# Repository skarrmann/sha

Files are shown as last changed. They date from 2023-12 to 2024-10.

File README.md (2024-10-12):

# Sha Keyboard

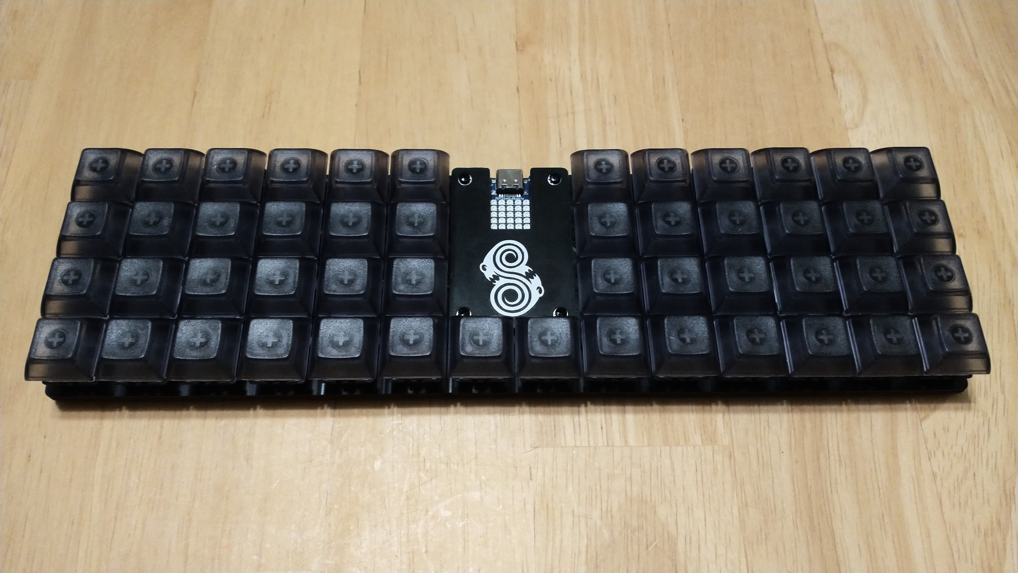
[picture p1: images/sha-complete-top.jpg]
Sha complete build top photo


Sha is a 50 key ortholinear keyboard, powered by either a [Waveshare RP2040-Zero](https://www.waveshare.com/rp2040-zero.htm) or [Waveshare RP2040-Matrix](https://www.waveshare.com/product/rp2040-matrix.htm).

## Project structure

* [`gerbers`](gerbers): Gerber files for PCB manufacturing
* [`graphics`](graphics): Source assets for PCB silkscreen
* [`kicad`](kicad): KiCad project files (schematics and PCB designs)
* [`kicad-libraries`](kicad-libraries): KiCad components and footprints
* [`images`](images): Images for project documentation
* [`firmware`](firmware): Firmware files

## PCBs

Two separate PCB designs are available for MX and Choc keyswitches, with their respective footprints and key spacing (MX: 19mm x 19mm, Choc: 18mm x 17mm).

The Waveshare RP2040-Zero/Matrix footprint uses surface-mount solder pads. The castellated pads of the MCU board are soldered directly onto the PCB.

**Each build uses two copies of the main PCB**. This PCB acts as both the logical PCB, and when flipped the long way, it acts as a bottom plate to be attached the logical PCB.

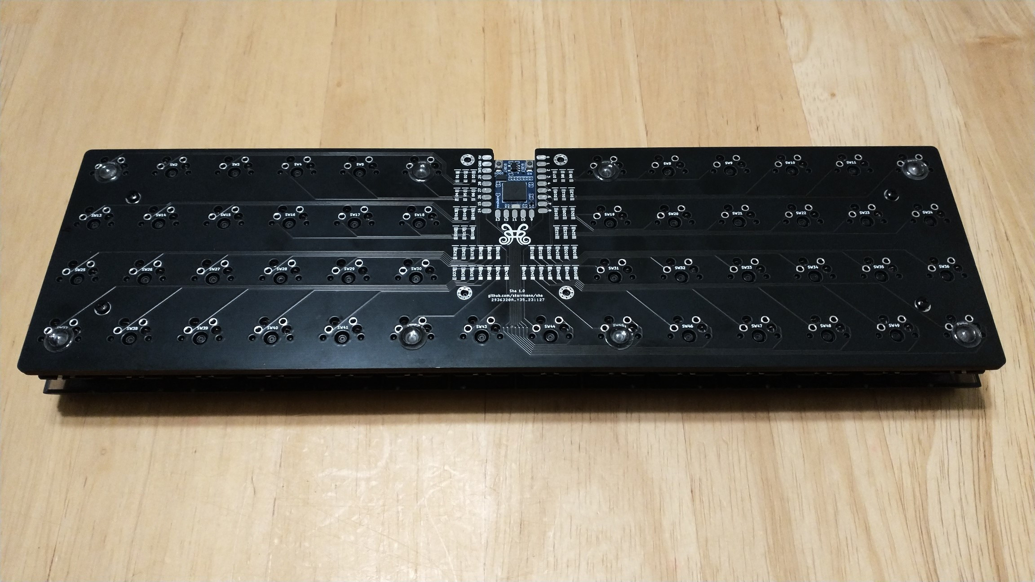
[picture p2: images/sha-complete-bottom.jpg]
Sha bottom plate attached


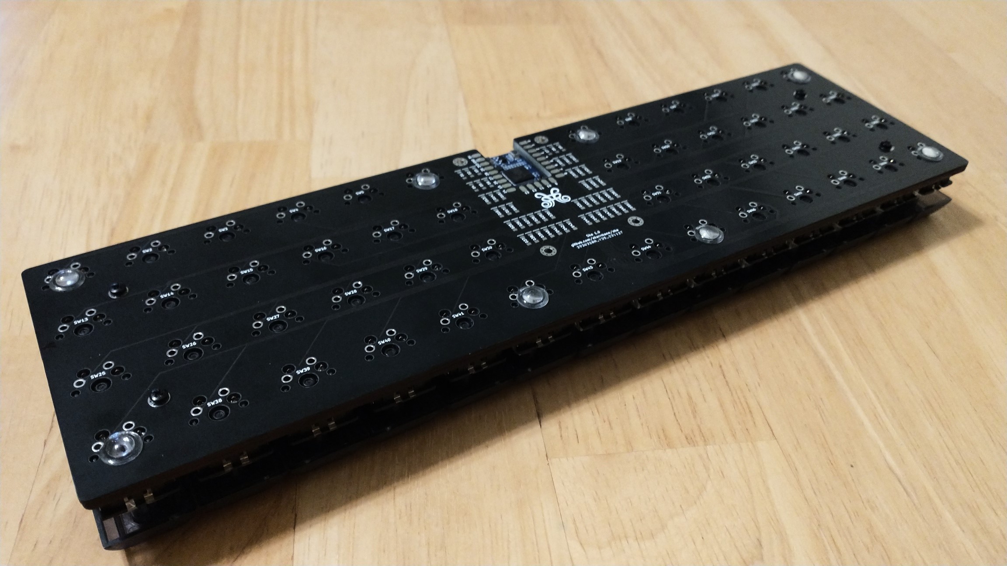
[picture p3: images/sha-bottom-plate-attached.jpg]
Sha bottom plate alternate shot


An optional top plate PCB is available in the gerber files. This top plate covers the diodes and the solder pads of the MCU board.

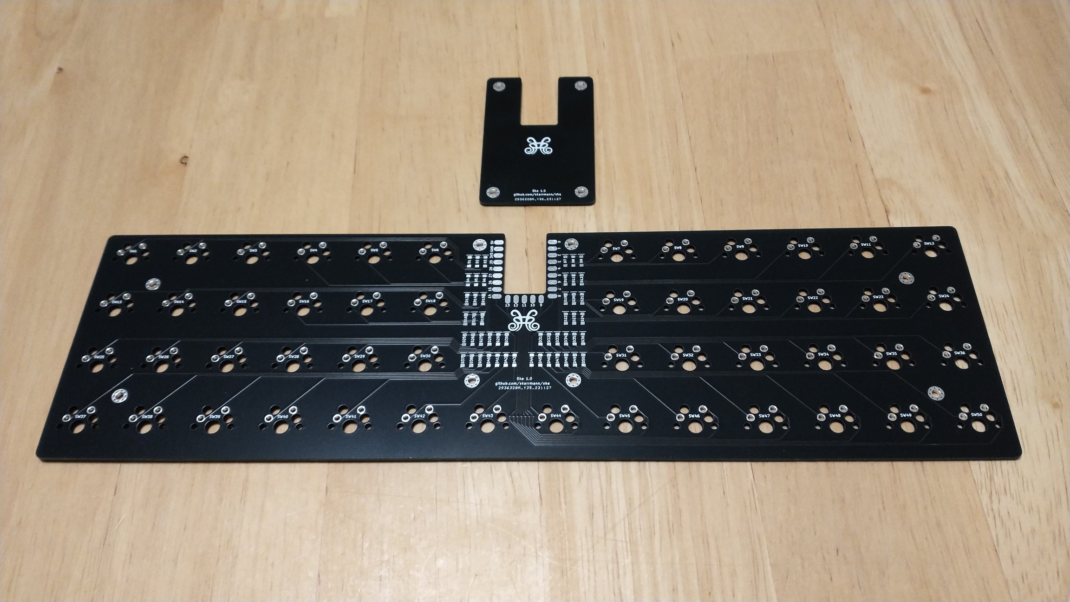
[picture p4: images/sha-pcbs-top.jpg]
Sha main and top plate PCBs


## Keyboard firmware

* KMK
    * Setup instructions and basic configuration is in this repo: [`firmware/kmk`](firmware/kmk)
* [QMK](https://github.com/qmk/qmk_firmware/tree/master/keyboards/sha)

## Bill of materials

Part | Purpose | Quantity | Notes
---- | ------- | -------- | -----
Main PCB  | circuit board and bottom plate | 2 | Send Gerber zip files to [JLCPCB](https://jlcpcb.com/)
Top plate PCB | protects diodes and MCU board | 1 |
Waveshare RP2040-Zero | Microcontroller board | 1 | Also supports Waveshare RP2040-Matrix
1N4148 SOD-123 | Diodes for keyboard row-column matrix | 50 |
Keyswitches |  | 50 | PCB mount (5 pin) switches recommended. For MX, any switches should work. For Choc, get Choc V1 switches.
Keycaps |  | 50 | For MX, any keycaps should work. For Choc, get those which fit Choc V1 18mm x 17mm
M2 6mm screws | 4 to secure main PCB and bottom plate PCB, 4 for top plate | 8 |
M2 nuts | 4 to secure main PCB and bottom plate PCB, 4 as spacers for top plate | 8 |
2mm tall rubber bumpons | Raise board above desk surface and provide skid resitance | 8 | 

Note the 4 M2 6mm screws and 4 M2 nuts just "friction fit" the top plate. To fully screw in the top plate, You could use 4 M2 8mm+ screws and 4 more M2 nuts. I meant to do this, but accidentally ordered the wrong size screws...!

## PCB manufacturing settings

These are the manufacturing settings I used when ordering from JLCPCB:

* **Base Material**: FR4
* **Layers**: 2
* **Dimensions**: (whatever the gerber file specifies)
* **PCB Qty**: 5
* **Different Design**: 1
* **Delivery Format**: Single PCB
* **PCB Thickness**: 1.6
* **PCB Color**: Black
* **Silkscreen**: White
* **Surface Finish**: LeadFree HASL-RoHS
* **Outer Copper Weight**: 1 oz
* **Gold Fingers**: No
* **Confirm Production File**: No
* **Flying Probe Test**: Fully Test
* **Castellated Holes**: No
* **Remove Order Number**: Specify a location

**IMPORTANT:** The PCB has ["JLCJLCJLCJLC" silkscreen text](https://jlcpcb.com/help/article/50-How-to-remove-order-number-from-your-PCB) on top side of the board. If you want to remove the order number from the boards or you want to print the PCBs with another manufacturer, then I recommend removing this silkscreen text from the `.kicad_pcb` file, and then regenerate the Gerber files.

## Build tips

* Solder the diodes first. Tin one side of all the diode solder pads, and then position each diode and re-heat this tinned pad to tack the diode in place. Then solder the other diode leg on each diode.
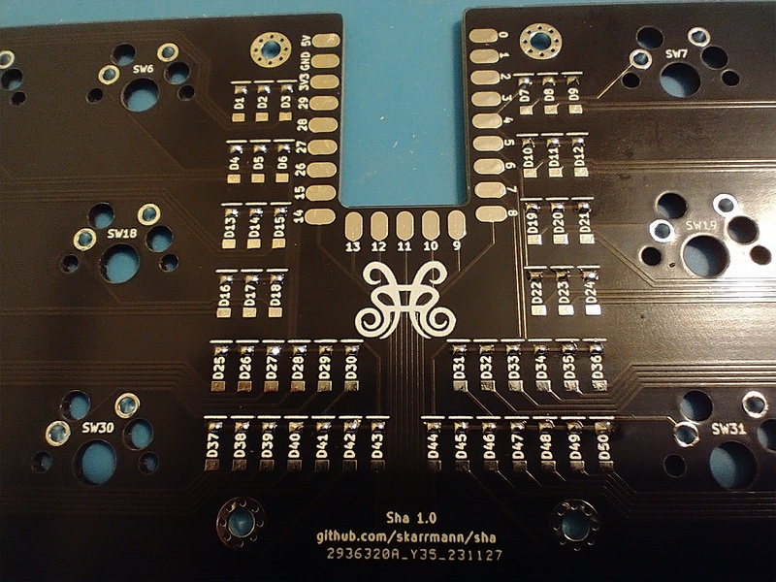
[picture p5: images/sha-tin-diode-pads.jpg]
Sha build, tin diode solder pads
     * 
* Once the diodes are fully soldered, do the microcontroller board next. Tape the board into position, and then solder the corner pads to tack it into place. Remove the tape and solder the remaining microcontroller board pads.
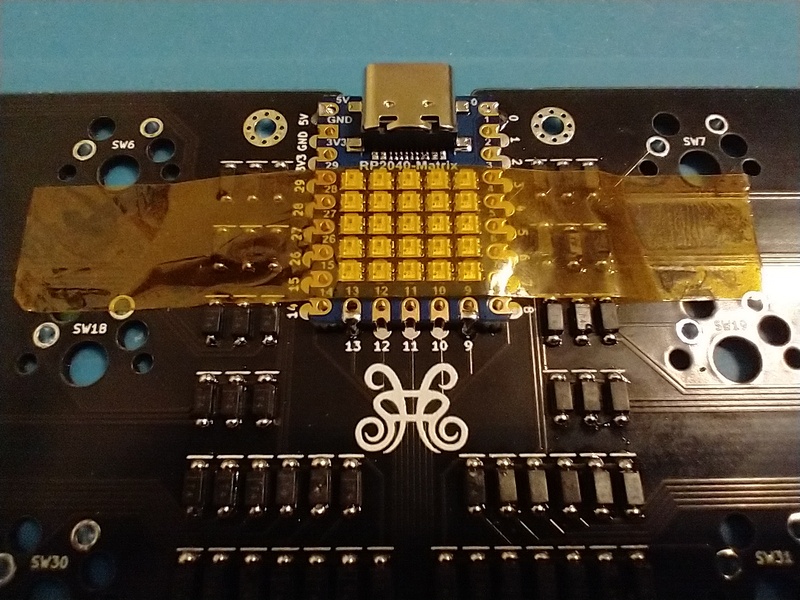
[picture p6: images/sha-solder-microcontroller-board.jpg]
Sha build, solder microcontroller board
     * 
* Last, solder in the switches. Note the switch PCB mounting pin holes were loose on my PCBs, but this might have been a manufacturing anomaly since I've never encountered this issue in other builds using this footprint. I worked around this by placing keycaps on the switches, then first soldering the four corner switches while applying pressure on top of the switch so it's fully inserted. Then I placed all the switches in their slots, pressed a spare PCB on top of the switches in a sandwich, flipped the board over, and soldered one leg of each switch while applying pressure to fully insert the switches. After confirming the switches were fully inserted, I soldered the other leg on each switch.
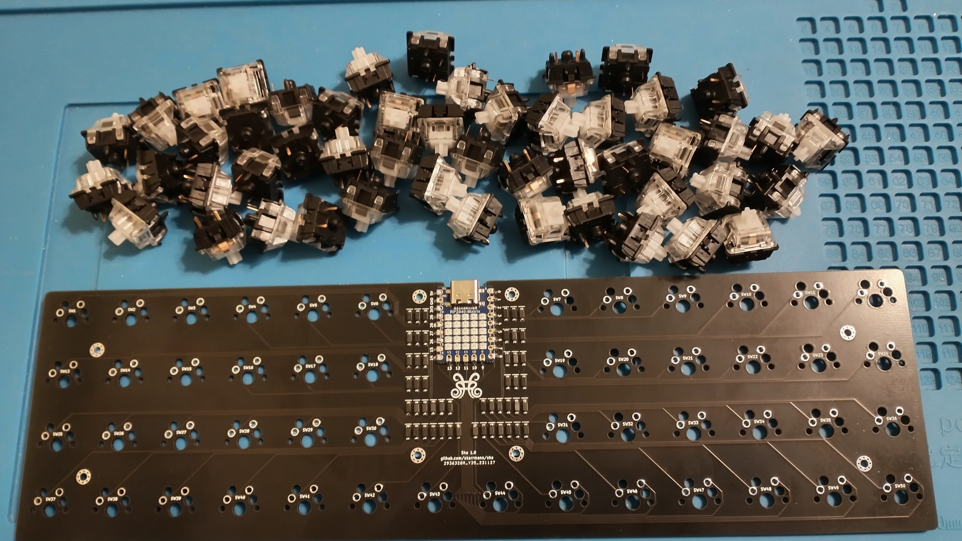
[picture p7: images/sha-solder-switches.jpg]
Sha build, solder switches
     * 
* For attaching the plates, use a single screw and hex nut to secure the bottom plate PCB to the main PCB. For the top plate, I just put a 6mm screw and hex through this plate's holes. The screw threads rest inside the PCB mounting holes, giving it a fiction fit. You could use other hardware to permanently screw in the top plate. See the BOM notes for suggestions.
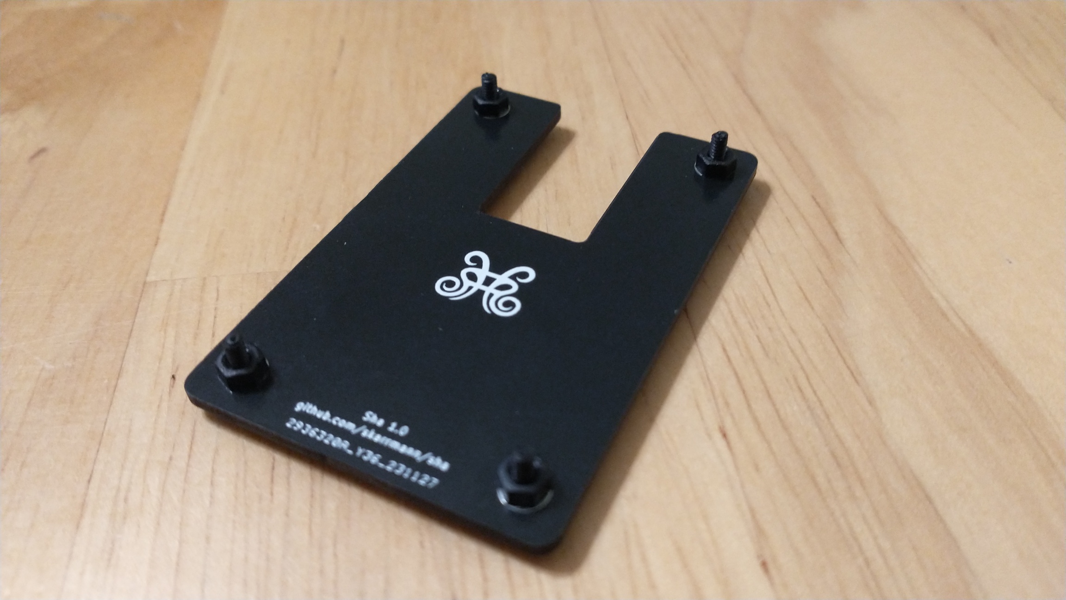
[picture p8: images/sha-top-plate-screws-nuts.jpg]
Sha build, screws nuts in top plate
     * 
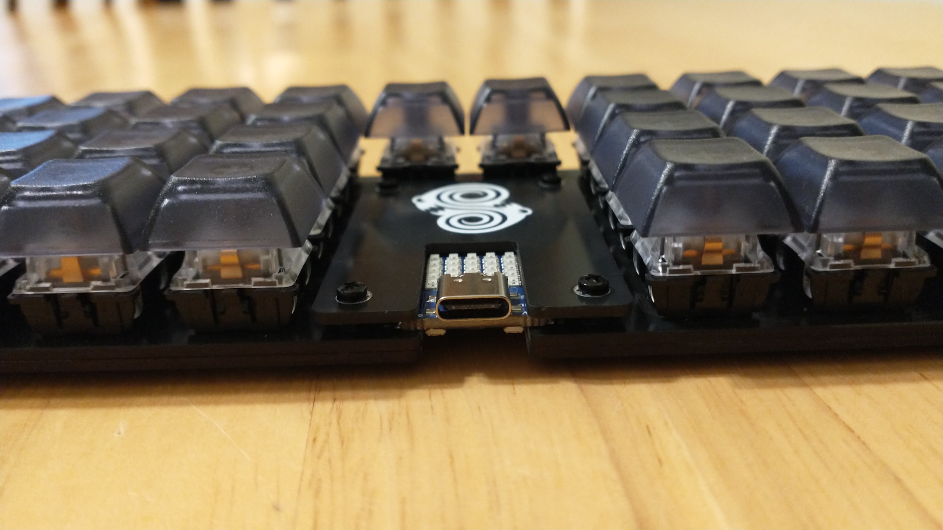
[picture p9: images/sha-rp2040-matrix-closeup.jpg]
Sha build, top plate friction fit
     * 

## KiCad project notes

The top plate was generated with the [Horizon Board Producer KiCad plugin](https://github.com/skarrmann/horizon#kicad-project-notes).

## Revision history

* **Sha 1.0** (2023-11-26)
     * Initial MX switch PCB design
* **Sha 1.1** (2024-10-09)
     * Create Choc switch PCB design
     * Update logos

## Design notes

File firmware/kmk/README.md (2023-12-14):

# Sha KMK Firmware

## Installation instructions

Apply these steps for either the RP2040-Zero or RP2040-Matrix:

1. Install CircuitPython:
    * https://circuitpython.org/board/waveshare_rp2040_zero/
2. Copy KMK firmware files:
    * https://github.com/KMKfw/kmk_firmware/blob/master/docs/en/Getting_Started.md
3. Copy the custom files:
    * [`kb.py`](kb.py)
    * [`main.py`](main.py)

Now customize the layout and features in [`main.py`](main.py) file, and save the updates on your board.

Currently, the layout does not use the RGB LEDs of the RP2040-Matrix. Using [KMK's RGB extension](http://kmkfw.io/docs/rgb), I could not get the LEDs to properly respond (they would only light up fully blue, red, or green). I will investigate and resolve this as time permits.

## Default keymap

The default keymap is my personal layout, used on both Sha and Horizon.

Keyboard layout editor URL: http://www.keyboard-layout-editor.com/#/gists/a50829674ed7be41396659aaf38d1ddb

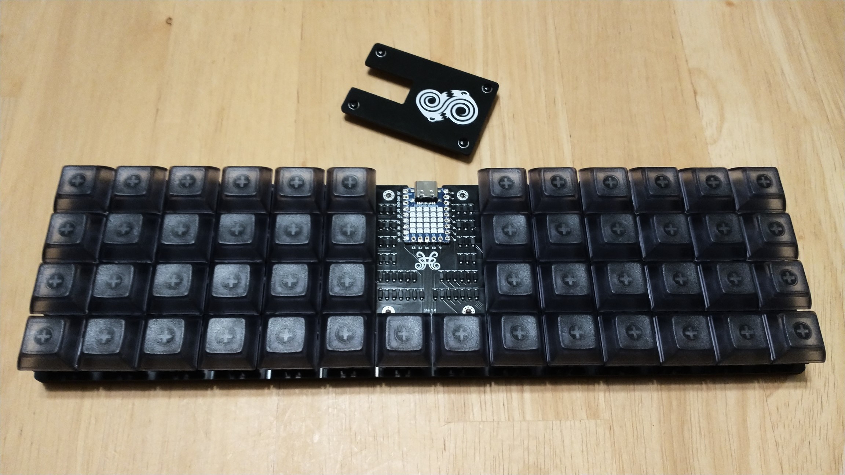
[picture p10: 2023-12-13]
images/sha-complete-top-cover-off.jpg

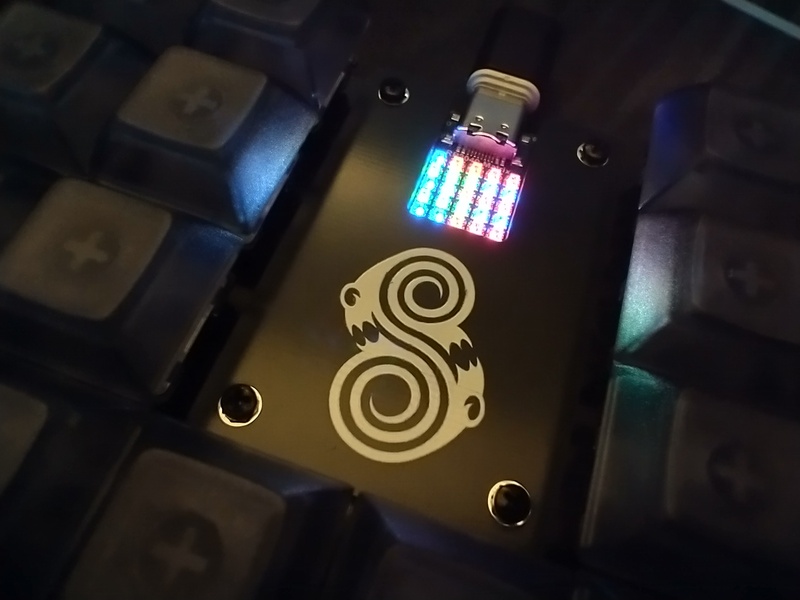
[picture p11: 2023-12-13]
images/sha-rgb.jpg

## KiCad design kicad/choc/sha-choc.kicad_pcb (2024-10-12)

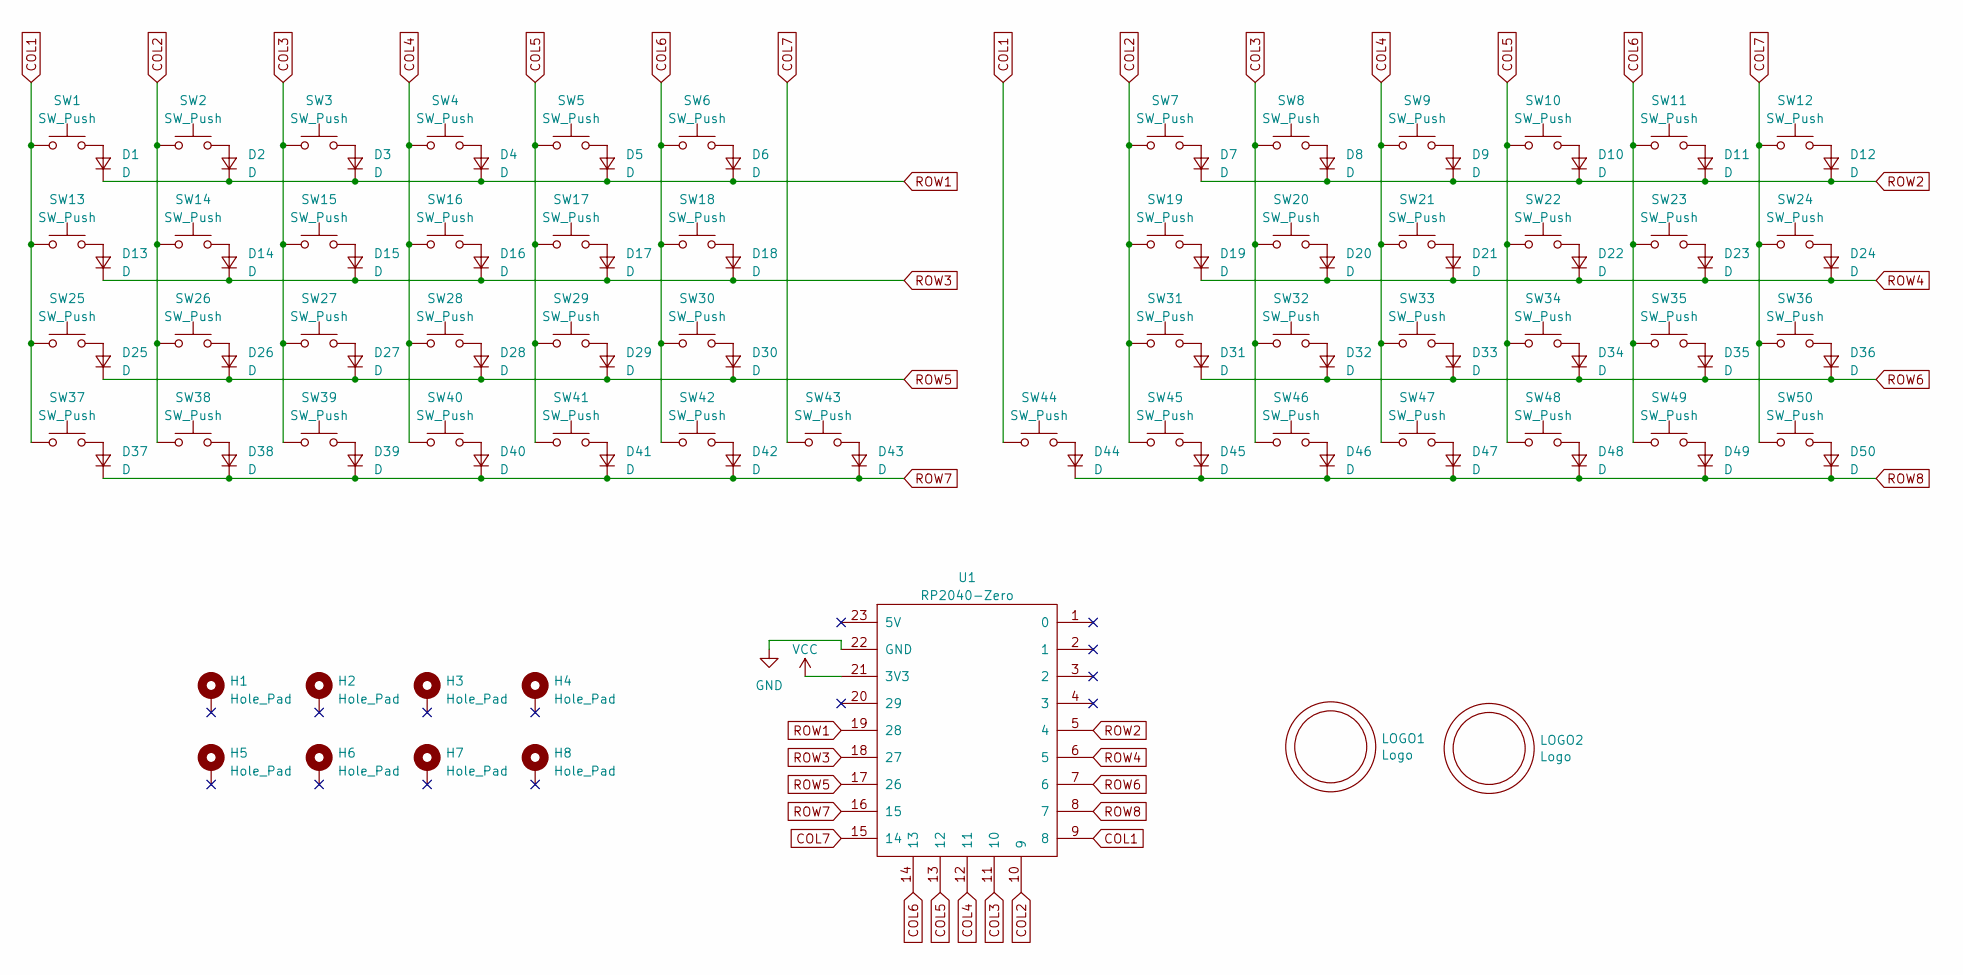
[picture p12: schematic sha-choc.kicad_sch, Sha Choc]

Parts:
D1, D2, D3, D4, D5, D6, D7, D8, D9, D10, D11, D12, D13, D14, D15, D16, D17, D18, D19, D20, D21, D22, D23, D24, D25, D26, D27, D28, D29, D30, D31, D32, D33, D34, D35, D36, D37, D38, D39, D40, D41, D42, D43, D44, D45, D46, D47, D48, D49, D50: D; D_SOD-123
H1, H2, H3, H4, H5, H6, H7, H8: Hole_Pad; Mount_M2
LOGO1: Logo; Logo_Sha
LOGO2: Logo; Logo_Sha_Name
SW1, SW2, SW3, SW4, SW5, SW6, SW7, SW8, SW9, SW10, SW11, SW12, SW13, SW14, SW15, SW16, SW17, SW18, SW19, SW20, SW21, SW22, SW23, SW24, SW25, SW26, SW27, SW28, SW29, SW30, SW31, SW32, SW33, SW34, SW35, SW36, SW37, SW38, SW39, SW40, SW41, SW42, SW43, SW44, SW45, SW46, SW47, SW48, SW49, SW50: SW_Push; SW_Choc_Reverse_Cutout
U1: RP2040-Zero; RP2040-Zero_SMD

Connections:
COL1: SW1.1, SW13.1, SW25.1, SW37.1, SW44.1, U1.9 (8)
COL2: SW2.1, SW7.1, SW14.1, SW19.1, SW26.1, SW31.1, SW38.1, SW45.1, U1.10 (9)
COL3: SW3.1, SW8.1, SW15.1, SW20.1, SW27.1, SW32.1, SW39.1, SW46.1, U1.11 (10)
COL4: SW4.1, SW9.1, SW16.1, SW21.1, SW28.1, SW33.1, SW40.1, SW47.1, U1.12 (11)
COL5: SW5.1, SW10.1, SW17.1, SW22.1, SW29.1, SW34.1, SW41.1, SW48.1, U1.13 (12)
COL6: SW6.1, SW11.1, SW18.1, SW23.1, SW30.1, SW35.1, SW42.1, SW49.1, U1.14 (13)
COL7: SW12.1, SW24.1, SW36.1, SW43.1, SW50.1, U1.15 (14)
GND: U1.22 (GND)
unnamed: D1.2 (A), SW1.2
unnamed: D2.2 (A), SW2.2
unnamed: D3.2 (A), SW3.2
unnamed: D4.2 (A), SW4.2
unnamed: D5.2 (A), SW5.2
unnamed: D6.2 (A), SW6.2
unnamed: D7.2 (A), SW7.2
unnamed: D8.2 (A), SW8.2
unnamed: D9.2 (A), SW9.2
unnamed: D10.2 (A), SW10.2
unnamed: D11.2 (A), SW11.2
unnamed: D12.2 (A), SW12.2
unnamed: D13.2 (A), SW13.2
unnamed: D14.2 (A), SW14.2
unnamed: D15.2 (A), SW15.2
unnamed: D16.2 (A), SW16.2
unnamed: D17.2 (A), SW17.2
unnamed: D18.2 (A), SW18.2
unnamed: D19.2 (A), SW19.2
unnamed: D20.2 (A), SW20.2
unnamed: D21.2 (A), SW21.2
unnamed: D22.2 (A), SW22.2
unnamed: D23.2 (A), SW23.2
unnamed: D24.2 (A), SW24.2
unnamed: D25.2 (A), SW25.2
unnamed: D26.2 (A), SW26.2
unnamed: D27.2 (A), SW27.2
unnamed: D28.2 (A), SW28.2
unnamed: D29.2 (A), SW29.2
unnamed: D30.2 (A), SW30.2
unnamed: D31.2 (A), SW31.2
unnamed: D32.2 (A), SW32.2
unnamed: D33.2 (A), SW33.2
unnamed: D34.2 (A), SW34.2
unnamed: D35.2 (A), SW35.2
unnamed: D36.2 (A), SW36.2
unnamed: D37.2 (A), SW37.2
unnamed: D38.2 (A), SW38.2
unnamed: D39.2 (A), SW39.2
unnamed: D40.2 (A), SW40.2
unnamed: D41.2 (A), SW41.2
unnamed: D42.2 (A), SW42.2
unnamed: D43.2 (A), SW43.2
unnamed: D44.2 (A), SW44.2
unnamed: D45.2 (A), SW45.2
unnamed: D46.2 (A), SW46.2
unnamed: D47.2 (A), SW47.2
unnamed: D48.2 (A), SW48.2
unnamed: D49.2 (A), SW49.2
unnamed: D50.2 (A), SW50.2
ROW1: D1.1 (K), D2.1 (K), D3.1 (K), D4.1 (K), D5.1 (K), D6.1 (K), U1.19 (28)
ROW2: D7.1 (K), D8.1 (K), D9.1 (K), D10.1 (K), D11.1 (K), D12.1 (K), U1.5 (4)
ROW3: D13.1 (K), D14.1 (K), D15.1 (K), D16.1 (K), D17.1 (K), D18.1 (K), U1.18 (27)
ROW4: D19.1 (K), D20.1 (K), D21.1 (K), D22.1 (K), D23.1 (K), D24.1 (K), U1.6 (5)
ROW5: D25.1 (K), D26.1 (K), D27.1 (K), D28.1 (K), D29.1 (K), D30.1 (K), U1.17 (26)
ROW6: D31.1 (K), D32.1 (K), D33.1 (K), D34.1 (K), D35.1 (K), D36.1 (K), U1.7 (6)
ROW7: D37.1 (K), D38.1 (K), D39.1 (K), D40.1 (K), D41.1 (K), D42.1 (K), D43.1 (K), U1.16 (15)
ROW8: D44.1 (K), D45.1 (K), D46.1 (K), D47.1 (K), D48.1 (K), D49.1 (K), D50.1 (K), U1.8 (7)
VCC: U1.21 (3V3)

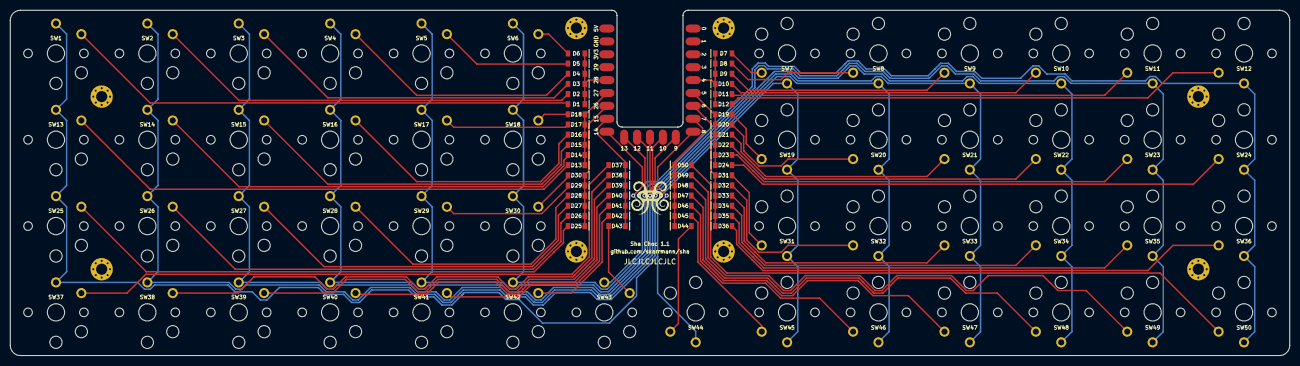
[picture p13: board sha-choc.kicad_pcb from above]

Board: 2 copper layers, 252.0 x 68.0 mm, 111 parts (1 on the bottom side), 65 nets.

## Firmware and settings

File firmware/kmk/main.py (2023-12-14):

from kb import KMKKeyboard
from kmk.keys import KC
from kmk.modules.layers import Layers
from kmk.extensions.media_keys import MediaKeys


keyboard = KMKKeyboard()

keyboard.extensions.append(MediaKeys())
keyboard.modules.append(Layers())

SYMTAB = KC.LT(1, KC.TAB, prefer_hold=True, tap_interrupted=True, tap_time=130)
FUNSPC = KC.LT(2, KC.SPC, prefer_hold=True, tap_interrupted=True, tap_time=200)

keyboard.keymap = [
    [   # Default (Colemak)
        KC.SCLN, KC.Q,    KC.W,    KC.F,    KC.P,    KC.G,                      KC.J,    KC.L,    KC.U,    KC.Y,    KC.QUOT, KC.MINS,
        KC.LSFT, KC.A,    KC.R,    KC.S,    KC.T,    KC.D,                      KC.H,    KC.N,    KC.E,    KC.I,    KC.O,    KC.RSFT,
        KC.LCTL, KC.Z,    KC.X,    KC.C,    KC.V,    KC.B,                      KC.K,    KC.M,    KC.COMM, KC.DOT,  KC.SLSH, KC.RCTL,
        KC.LALT, KC.LGUI, KC.NO,   KC.NO,   KC.DEL,  SYMTAB,  KC.ESC,  KC.ENT,  FUNSPC,  KC.BSPC, KC.NO,   KC.NO,   KC.RGUI, KC.RALT
    ],
    [   # Symbol
        KC.COLN, KC.N1,   KC.N2,   KC.N3,   KC.N4,   KC.N5,                     KC.N6,   KC.N7,   KC.N8,   KC.N9,   KC.DQUO, KC.UNDS,
        KC.HASH, KC.EXLM, KC.LPRN, KC.RPRN, KC.DLR,  KC.AMPR,                   KC.PIPE, KC.EQL,  KC.LCBR, KC.RCBR, KC.N0,   KC.GRV,
        KC.TILD, KC.AT,   KC.LBRC, KC.RBRC, KC.PLUS, KC.PERC,                   KC.CIRC, KC.ASTR, KC.LABK, KC.RABK, KC.QUES, KC.BSLS,
        KC.TRNS, KC.TRNS, KC.TRNS, KC.TRNS, KC.TRNS, KC.TRNS, KC.TRNS, KC.TRNS, KC.SPC,  KC.TRNS, KC.TRNS, KC.TRNS, KC.TRNS, KC.TRNS
    ],
    [   # Function
        KC.TRNS, KC.F1,   KC.F2,   KC.F3,   KC.F4,   KC.PSCR,                   KC.SLCK, KC.HOME, KC.PGDN, KC.PGUP, KC.END,  KC.TRNS,
        KC.TRNS, KC.F5,   KC.F6,   KC.F7,   KC.F8,   KC.INS,                    KC.CAPS, KC.LEFT, KC.DOWN, KC.UP,   KC.RGHT, KC.TRNS,
        KC.TRNS, KC.F9,   KC.F10,  KC.F11,  KC.F12,  KC.APP,                    KC.NLCK, KC.MUTE, KC.VOLD, KC.VOLU, KC.PAUS, KC.TRNS,
        KC.TRNS, KC.TRNS, KC.TRNS, KC.TRNS, KC.TRNS, KC.TAB,  KC.TRNS, KC.TRNS, KC.SPC,  KC.TRNS, KC.TRNS, KC.TRNS, KC.TRNS, KC.TRNS
    ]
]


if __name__ == '__main__':
    keyboard.go()

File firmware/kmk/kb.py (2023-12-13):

import board
from kmk.kmk_keyboard import KMKKeyboard as _KMKKeyboard
from kmk.scanners import DiodeOrientation


class KMKKeyboard(_KMKKeyboard):
    col_pins = (board.GP8, board.GP9, board.GP10, board.GP11, board.GP12, board.GP13, board.GP14)
    row_pins = (board.GP28, board.GP4, board.GP27, board.GP5, board.GP26, board.GP6, board.GP15, board.GP7)
    diode_orientation = DiodeOrientation.COLUMNS
    rgb_pixel_pin = board.GP16
    rgb_num_pixels = 25

    coord_mapping = [
     0,  1,  2,  3,  4,  5,          8,  9, 10, 11, 12, 13,
    14, 15, 16, 17, 18, 19,         22, 23, 24, 25, 26, 27,
    28, 29, 30, 31, 32, 33,         36, 37, 38, 39, 40, 41,
    42, 43, 44, 45, 46, 47, 48, 49, 50, 51, 52, 53, 54, 55
    ]

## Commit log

2023-11-27 Clean up Sha logo
    [sha-mx.kicad_pcb]
2023-11-29 Center PCB silkscreen text
    [sha-mx.kicad_pcb]
2023-12-13 Add another bottom plate photo and clean up readme
2023-12-15 Finish notes on mounting top plate
2024-10-12 Create Choc switch design, update logos
    [sha-choc.kicad_pcb, sha-choc.kicad_sch, sha-mx.kicad_pcb]
2024-10-12 Remove unneeded cutout line
    [sha-choc.kicad_pcb]
